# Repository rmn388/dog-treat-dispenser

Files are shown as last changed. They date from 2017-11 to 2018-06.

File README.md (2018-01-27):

# dog-treat-dispenser

All of the code and CAD models to make the Dog Treat Dispenser that is featured in the Feb/March 2018 Issue of Make Magazine.

Video of the device in action: https://www.youtube.com/watch?v=wkbKYwNOw7A

Blog post with a high level overview of the project: http://richnelson.me/side-project/2015/12/25/treat-dispenser.html

##### Setup Table of Contencts
- [1. Getting Started](#gettingstarted)
- [2. Raspberry Pi Setup](#raspberrypi)  

<a name="gettingstarted"/>

## 1. Getting Started

This detailed tutorial section is a work in progress.

This tutorial will not cover:
- Fabrication of the parts
- Basic setup of the Raspberry Pi
- Setup of Arduino IDE
- Port forwarding for your specific router

But may provide links to external resources, as there is great documentation for these tasks.

This tutorial will cover:
- Setting up the server on the Raspberry Pi
- Configuring your Twilio phone number
- Wiring up the components
- Assembly of the device

If there are any issues, please report them in the bug tracker for this repository.

<a name="raspberrypi"/>

## 2. Raspberry Pi Setup
IMPORTANT: Make sure the power supply you use for four Raspberry Pi has a high enough current rating.  2.5A is recommended, but I find 2A+ to keep things working smoothly.  A Raspberry Pi that is not getting enough current can act unpredictably when processes ramp up and the current draw increases,  I learned this the hard way trying to debug an issue for a week that was caused by an inadequate power supply and I've talked to many people with similar experiences.

Log onto your Raspberry Pi with Raspbian Stretch installed.  _(A Raspberry Pi 3 Model B with Raspbian stretch in my case)_.  You can plug directly into the Pi with an HDMI screen, mouse, and keyboard.  Or if the Pi is already on your network you can connect via SSH or VNC ([official documentation here](https://www.raspberrypi.org/documentation/remote-access/)),  I'll be using VNC for this tutorial.

### Downloading the Repository and setting up the virtual environment

Log on to your Pi and make sure you are connected to you home network.

Then Open up a terminal.

Raspberry Pi open terminal

Create a local copy of the dog-treat-dispenser repository using the following command.

Terminal Input:
```bash
git clone https://github.com/rmn388/dog-treat-dispenser
```
Expected Output:
```bash
Cloning into 'dog-treat-dispenser'...
remote: Counting objects: 66, done.
remote: Total 66 (delta 0), reused 0 (delta 0), pack-reused 66
Unpacking objects: 100% (66/66), done.
```

cd into the new directory

Terminal Input:
```bash
cd dog-treat-dispenser
```
Current Location _(to left of cursor)_:
```bash
~/dog-treat-dispenser $
```

You can use ls to list the files in the directory

Input:
```bash
ls
```

Expected Output:
```bash
app.py  arduino  bin  cad  README.md  requirements.txt
```

We're going to install virtualenv so that we can create a virtual environment to manage the packages and versions for the project. This step is technically not necessary, but may help to avoid headaches later with dependency issues, and it is good practice so that the libraries don't interfere with other projects.

Input:
```bash
python3 -m pip install --user virtualenv
```

Expected Output:
```bash
Collecting virtualenv
  Downloading virtualenv-15.1.0-py2.py3-none-any.whl (1.8MB)
    100% |████████████████████████████████| 1.8MB 64kB/s
Installing collected packages: virtualenv
Successfully installed virtualenv-15.1.0
```

Making sure you are still in the project directory create a virtual environment

Input:
```bash
python3 -m virtualenv env
```

Expected Output:
```bash
Using base prefix '/usr'
New python executable in /home/pi/dog-treat-dispenser/env/bin/python3
Also creating executable in /home/pi/dog-treat-dispenser/env/bin/python
Installing setuptools, pip, wheel...done.
```

You should also see a new folder in your project directory called env

Lastly to activate our virtual environment:
```bash
source env/bin/activate
```

Now your in the terminal your username/current directory should be prefaced with (env):
```bash
(env) pi@raspberrypi:~/dog-treat-dispenser $
```

Whenever we run the project we'll need to be in this environment, to deactivate the environment simply type: deactivate

### Setting up the Dependencies and Config

To install the python dependencies enter:
```bash
pip install -r requirements.txt
```
The installation should finish with the following message:
```bash
Successfully installed Flask-0.12.1 Jinja2-2.10 MarkupSafe-1.0 PyJWT-1.5.3 RPi.GPIO-0.6.3 Werkzeug-0.14.1 certifi-2018.1.18 chardet-3.0.4 click-6.7 dropbox-6.8.0 idna-2.6 itsdangerous-0.24 picamera-1.13 pysocks-1.6.8 pytz-2017.3 requests-2.18.4 six-1.11.0 twilio-6.8.3 typing-3.6.4 urllib3-1.22
```

 Next we need to create a configuration file which will contain all of the settings for your project.

 Create a file called config.py in the root directory of your project.

This can be done with the terminal text editor of choice, like nano or vi:
```bash
nano config.py
```
```bash
vi config.py
```

**OR**

With a GUI by navigating to the project folder and creating the file.

Copy the following into the new file and save it.

 ```python
 #config

#Private API credentials
dropbox_access_token = "################################################################" #Your Dropbox Access Token
dropbox_folder = "dog_photos" #Dropbox folder where you want to save th photos, you must create this folder in your Dropbox
twilio_phone_number = "+###########" #Your unique Twilio phone number
twilio_account_sid = "#################################" #Your Twilio Account SID
twilio_auth_token  = "################################" #Your Twilio Auth Token

#Default settings
port = 2244
img_width = 3280
img_height = 2464
alert_GPIO_pin = 17
treat_GPIO_pin = 18
alert_reps = 3
num_treats = 1
```

We will fill in those API credentials soon, but with that file made we're ready to run the flask server as the first test!

In the terminal enter:
```bash
python app.py
```
Expected Output:
```bash
* Running on http://0.0.0.0:2244/ (Press CTRL+C to quit)
* Restarting with stat
* Debugger is active!
* Debugger PIN: 782-553-230
```

This means the server is running!  The first output line "Running on ..." Shows the URL of the server on the local machine.  So you can open up a browser window on the pi and type it in, you should see this.

Flask server test

Congratulations you have a live Python Flask webserver! Flask is a great lightweight web framework for Python.

You can also visit the server from any computer that is on the same network, but you will need to use the Pi's local network IP address instead of 0.0.0.0.  To find the Pi's IP address type __ifconfig__ in the terminal, it is the "inet" address for me in the wlan section since I'm on wifi.  It usually starts with 192.168.  So you can substitute that for the "0.0.0.0" to test the server from any computer on your network.

When you visit the URL the terminal window that is running the server should show a log like this:
```bash
127.0.0.1 - - [25/Jan/2018 05:15:47] "GET / HTTP/1.1" 200 -
```

To shutdown the server press Ctrl-C

## Configure your PI with a static IP address for your local network

You can already access the server form the internet, now you'll need to set up port forwarding on your router to direct traffic on a particular port to your server.

By default your router will randomly assign an IP address to your Pi, but for this project or any web server we need to make sure it is always the same.  First you need to configure your Raspberry Pi with a static IP address.  This can be done it the router settings so it always assigns the same IP address to the Pi, feel free to do that if you know how, but for this tutorial we will do it from the Pi.

To find the current IP address of your Raspberry Pi

Terminal Input:
```bash
ifconfig
```
Your looking for the inet address for the network device that you're using. If you on wifi it will be something like **wlan0**.

```bash
wlan0: flags=4163<UP,BROADCAST,RUNNING,MULTICAST>  mtu 1500
        inet 192.168.0.10  netmask 255.255.255.0  broadcast 192.168.0.255
        inet6 fe80::110e:7c25:e726:57ba  prefixlen 64  scopeid 0x20<link>
        ether b8:27:eb:61:ee:df  txqueuelen 1000  (Ethernet)
        RX packets 1681  bytes 95988 (93.7 KiB)
        RX errors 0  dropped 0  overruns 0  frame 0
        TX packets 2004  bytes 2621320 (2.4 MiB)
        TX errors 0  dropped 0 overruns 0  carrier 0  collisions 0
```

In this case our local IP address is 192.168.0.10 it was usually start with 192.168, the 3rd number can change router by router, and the last number will be different for all of the devices on your network.

You will need to remember the network device in my case **wlan0** and the first 3 sections of the IP address in my case **192.168.0**

Edit the DHCPCD configuration file with your proffered text editor.   I'll be using vi but you can use nano, or navigate to edit the file with the graphic interface.

Terminal Input:
```bash
sudo vi /etc/dh
```

There should be sample configuration settings commented out by #s. Add the following two lines to configure your static IP address, but make sure to substitute your information from the last step for the interface and first 3 segments of the IP address.
```
interface wlan0
static ip_address=192.168.0.220
```

I choose 220 but it can technically be any number between 1-254.  The caveat is that there is a chance that your router already assigned the IP to another device,  usually the lower number are assigned first, so number above 200 are safer.  In your router settings you can limit the dynamically assigned IPs to a certain range, but this shouldn't be necessary.

Save the file, then to restart the pi so that the new changes take effect.

Terminal Input to restart:
```bash
sudo reboot now
```

If you're connected remotely through SSH or VNC,  you'll have to connect using the new IP address, in my case 192.168.0.220

### Configure Your Router for Port Forwarding

Note: This detailed setup tutorial is a work in progress next sections will be setting up the camera and API credentials.
---

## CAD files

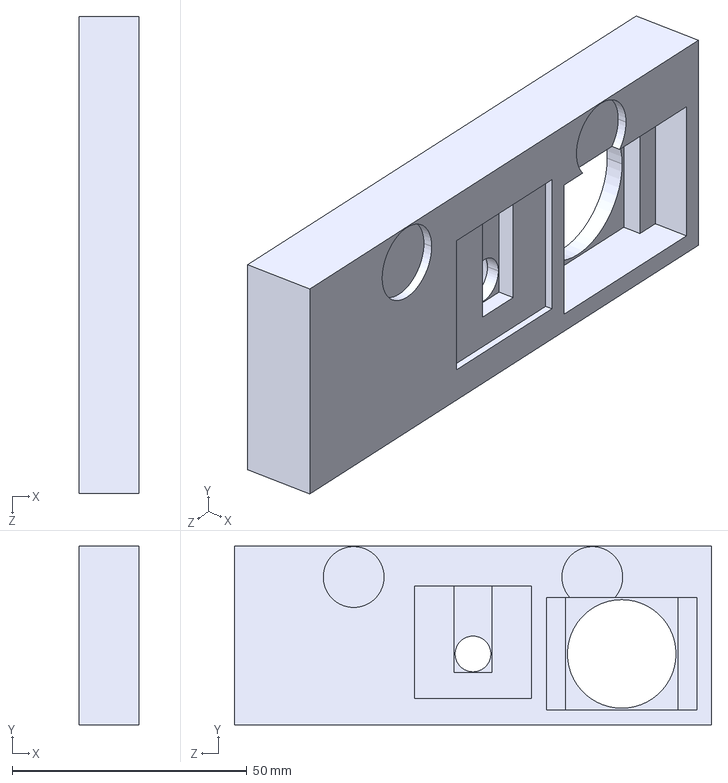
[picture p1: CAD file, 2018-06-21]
cad/STEP/Box Camera Mount.STEP
12.7 x 38.1 x 101.6 mm

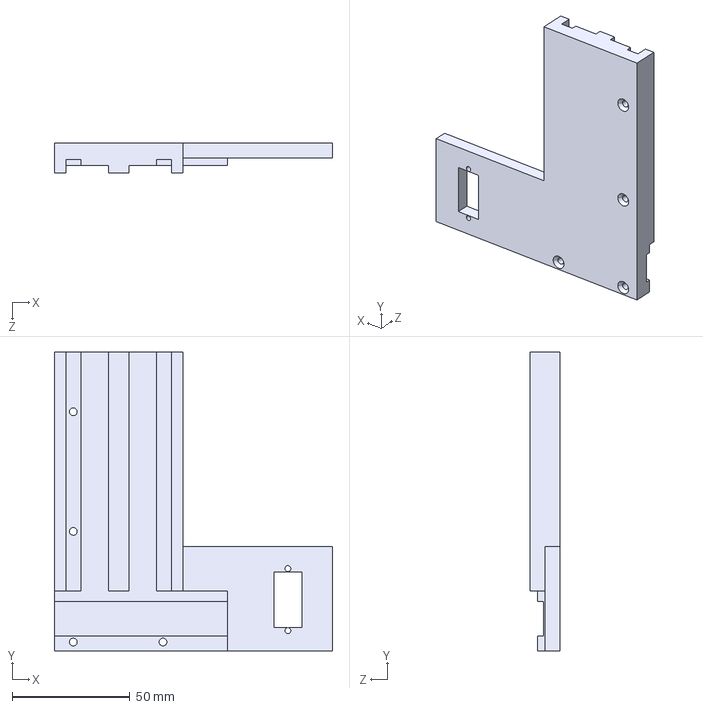
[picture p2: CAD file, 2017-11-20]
cad/STEP/Dispenser Left Side.STEP
118.3 x 127.0 x 12.7 mm

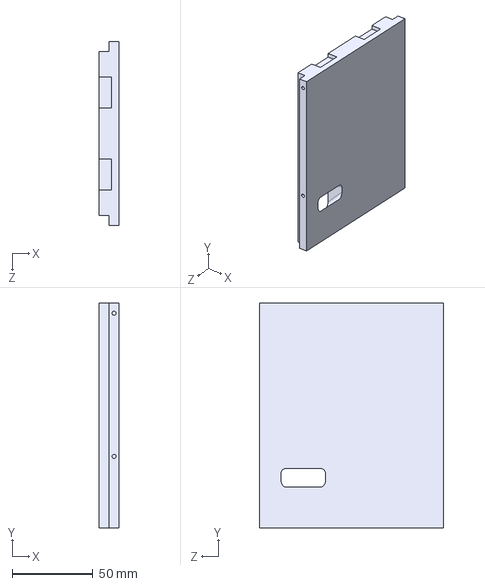
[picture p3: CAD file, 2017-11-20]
cad/STEP/Box Front.STEP
12.7 x 139.7 x 114.3 mm

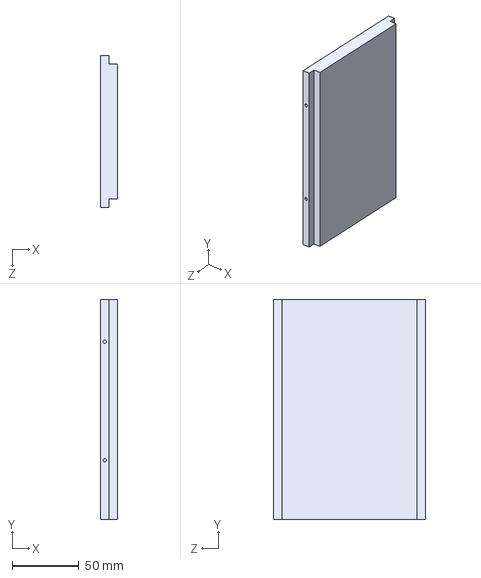
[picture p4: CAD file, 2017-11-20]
cad/STEP/Box Back.STEP
12.7 x 165.1 x 114.3 mm

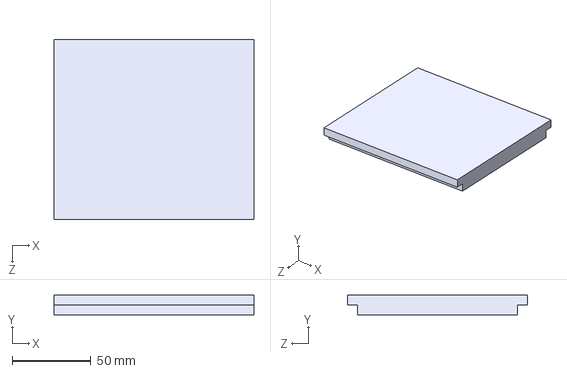
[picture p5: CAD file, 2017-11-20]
cad/STEP/Box Bottom.STEP
127.0 x 12.7 x 114.3 mm

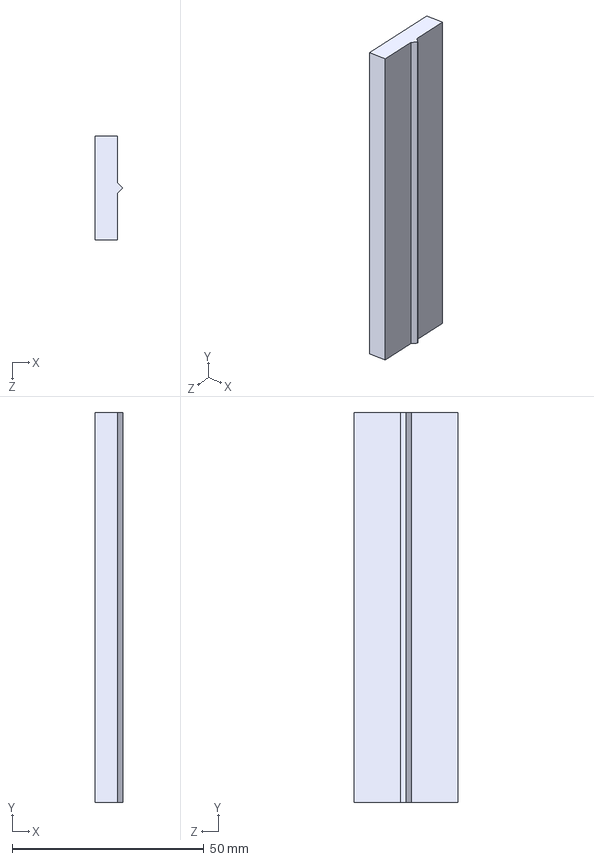
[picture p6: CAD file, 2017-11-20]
cad/STEP/Dispenser Back.STEP
7.28 x 101.6 x 27.2 mm

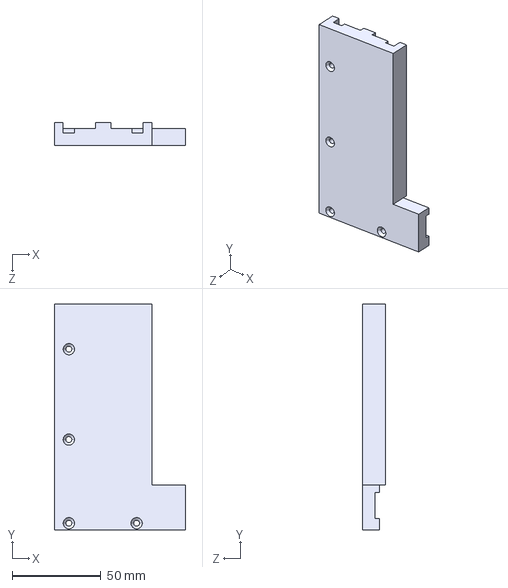
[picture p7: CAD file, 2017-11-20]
cad/STEP/Dispenser Right Side.STEP
73.7 x 127.0 x 12.7 mm

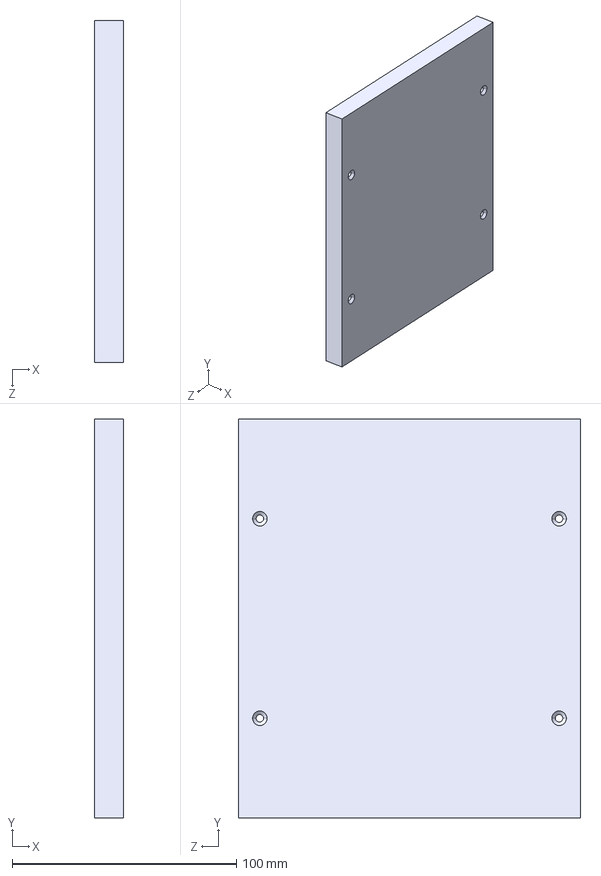
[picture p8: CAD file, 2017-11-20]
cad/STEP/Box Right Side.STEP
12.7 x 177.8 x 152.4 mm

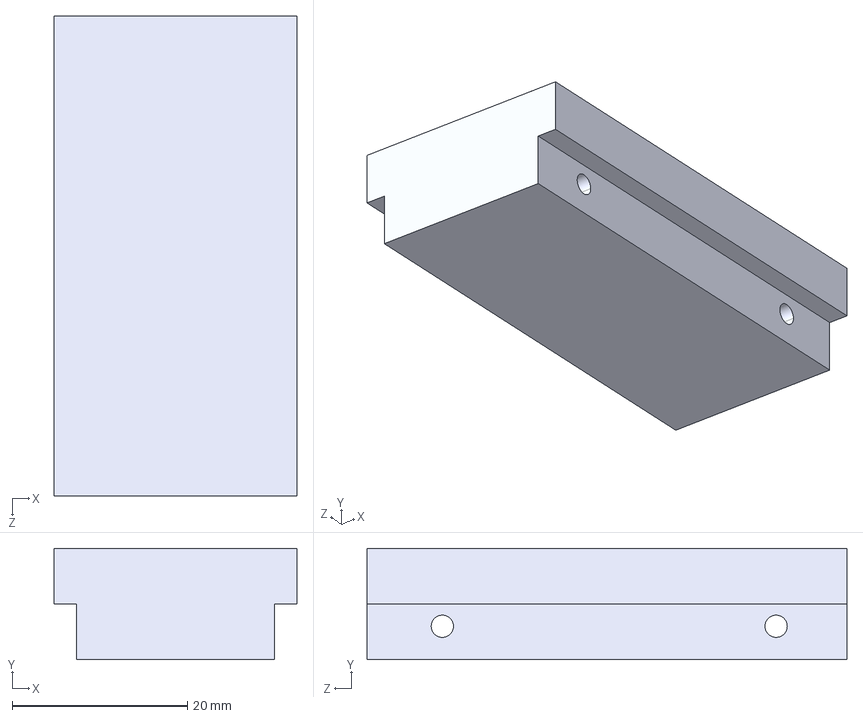
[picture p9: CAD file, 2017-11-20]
cad/STEP/Dispenser Bottom.STEP
27.7 x 12.7 x 54.8 mm

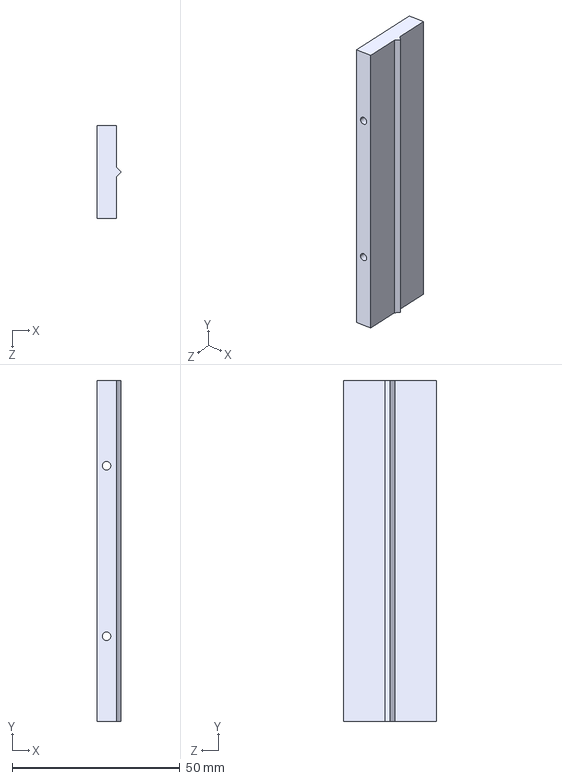
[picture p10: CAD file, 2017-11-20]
cad/STEP/Dispenser Front.STEP
7.28 x 101.6 x 27.7 mm

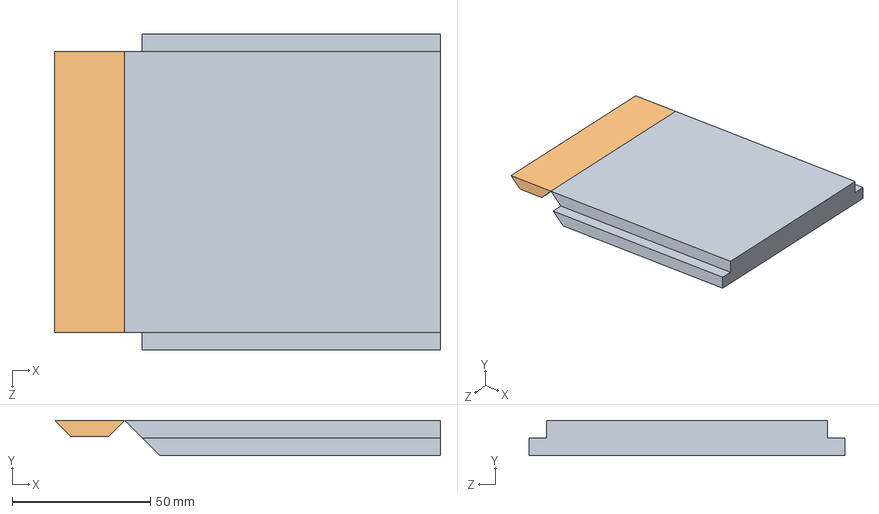
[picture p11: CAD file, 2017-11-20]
cad/STEP/Box Top Live hinge.STEP
139.7 x 12.7 x 114.3 mm
top
hinge

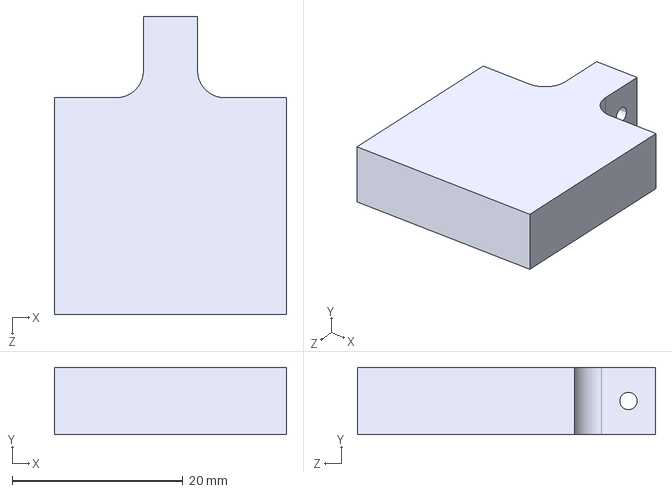
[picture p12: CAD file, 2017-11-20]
cad/STEP/Dispenser Slide.STEP
27.2 x 7.87 x 34.9 mm

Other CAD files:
cad/STEP/Box Left Side.STEP
cad/STL/Box Back.STL
cad/STL/Box Bottom.STL
cad/STL/Box Camera Mount.STL
cad/STL/Box Front.STL
cad/STL/Box Left Side.STL
cad/STL/Box Right Side.STL
cad/STL/Box Top Live hinge.STL
cad/STL/Dispenser Back.STL
cad/STL/Dispenser Bottom.STL
cad/STL/Dispenser Front.STL
cad/STL/Dispenser Left Side.STL
cad/STL/Dispenser Right Side.STL
cad/STL/Dispenser Slide.STL

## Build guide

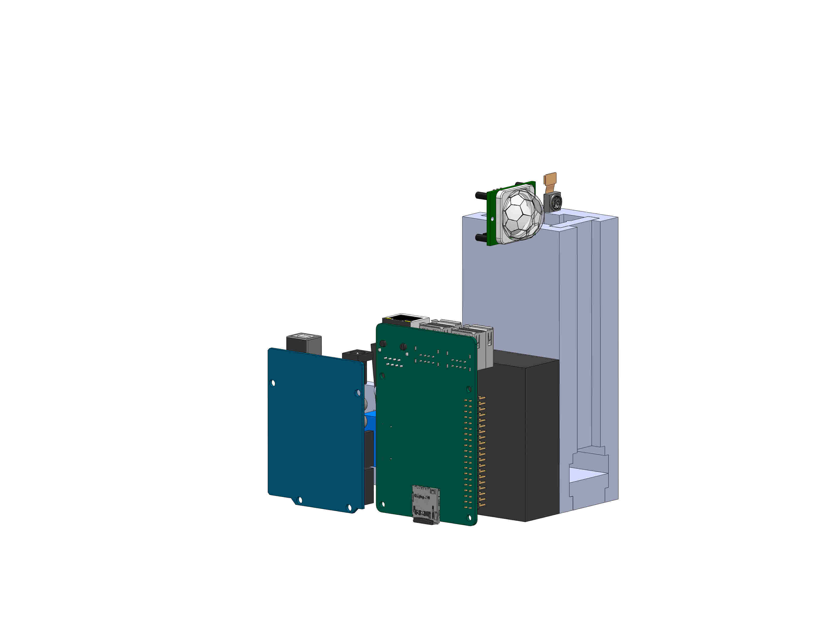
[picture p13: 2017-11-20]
cad/Assembly 3 - Electronics.JPG

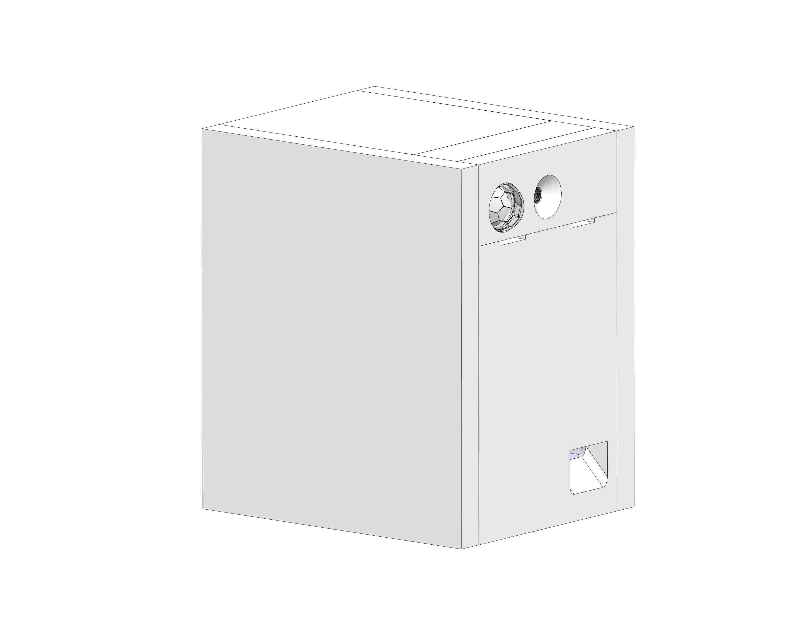
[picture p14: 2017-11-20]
cad/Assembly 4 - Box.JPG

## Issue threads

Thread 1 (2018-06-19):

missing file

reid23, 2018-06-19:
The cad for the piece of the box that holds the motion detector and the camera is not posted (or I can't find it).  can you tell me where it is or upload it if it is not yet?  thanks!

Rich-Nelson, 2018-06-21:
Good catch,  I just added the files in the cad folder under the names Box Camera Mount.STL and Box Camera Mount.STEP

Rich-Nelson, 2018-06-21:
Good catch, I just added the files to the CAD folder under the name Box Camera Mount.STL and Box Camera Mount.STEP

Closed 2018-06-21.

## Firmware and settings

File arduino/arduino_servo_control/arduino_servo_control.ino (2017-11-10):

#include <Servo.h>

Servo piston;
int pos_in = 180;
int pos_alert = 150;
int pos_out = 15;
int alert_input = 0;
int old_alert_input = 0;
int treat_input = 0;
int old_treat_input = 0;
const int pi_alert = 7; //17 on pi
const int pi_treat = 8; //18 on pi

void setup() {
  piston.attach(A0); //Servo Output
  piston.write(pos_in);
  piston.detach();
  pinMode(pi_treat, INPUT); //Raspberry Pi treat pin
  pinMode(pi_alert, INPUT); //Raspberry Pi alert pin
  
}


void loop() {
  alert_input = digitalRead(pi_alert);
  treat_input = digitalRead(pi_treat);
  if (alert_input > old_alert_input){
    piston.attach(3);
      for (int x=0; x<3; x++){
      
      piston.write(pos_alert);
      delay(150);
      piston.write(pos_in);
      delay(150);
    }
   piston.detach(); 
  }
  
  if (treat_input > old_treat_input){
    piston.attach(3);
    piston.write(pos_out);
    delay(1000);
    piston.write(pos_in);
    delay(1000);
    piston.detach(); 
  }
  
  old_alert_input = alert_input;
  old_treat_input = treat_input;
}

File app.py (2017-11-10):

from flask import Flask, request
from twilio.twiml.messaging_response import MessagingResponse, Message
from twilio.rest import Client
from bin.dispenser import Dispenser
from bin.photo import Photo
import config as c

app = Flask(__name__)

@app.route('/')
def index():
    return '<h1>Treat Server is live!</h1>'

@app.route("/receive_message", methods=['GET', 'POST'])
def receive_message():
    message = request.values
    sms_sender_number = message.get('From')
    sms_body = message.get('Body')
    print(("{}: {}").format(sms_sender_number, sms_body))
    
    dispenser = Dispenser(c.alert_GPIO_pin, c.treat_GPIO_pin,)
    dispenser.alert_pet(c.alert_reps)
    print("Pet alerted")
    
    photo = Photo()
    img_filename = photo.take_picture(c.img_width, c.img_height)
    print("Photo filename:", img_filename)
    
    dispenser.give_treat(c.num_treats)
    print("Treat given")
    
    img_url = photo.upload_to_dropbox(c.dropbox_access_token,
                                      c.dropbox_folder)
    print("Image url:", img_url)
    
    twilio_client = Client(c.twilio_account_sid, c.twilio_auth_token)
    response = twilio_client.messages.create(to= sms_sender_number,
                                             from_= c.twilio_phone_number,
                                             body= "",
                                             media_url= img_url)
    print("Message sent")
    
    #photo.delete_photo()

    resp = MessagingResponse()

    return str(resp)

if __name__ == "__main__":
    app.run(host="0.0.0.0", port=c.port, debug=True)

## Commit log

2017-11-20 Added CAD models and updated README
    [Box Back.STEP, Box Back.STL, Box Bottom.STEP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]
2017-11-20 Added assembly renderings
2017-11-21 Fixed file name generation on Photo Class init
    [photo.py]
2018-06-21 Added CAD files for the camera mount under the name Box Camera Mount.STL and Box Camera Mount.STEP
    [Box Camera Mount.STEP, Box Camera Mount.STL]
